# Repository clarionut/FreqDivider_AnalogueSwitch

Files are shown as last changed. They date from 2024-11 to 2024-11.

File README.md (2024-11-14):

# Frequency Divider / Analogue Switch

This repository contains details of synthesiser module providing a 4-stage frequency divider linked to three 2-in 2-out analogue changeover switches.

DividerSwitch

The frequency divider comprises two CD4027B Dual J-K flip-flops with each stage wired as a T-type flip-flop. Each stage toggles its state on the rising edge of its clock signal, converting the incoming pulse train into a square wave of half the incoming frequency. By default the output of each stage is normalled to the input of the next, so a single clock input can give four outputs of 1/2, 1/4, 1/8 and 1/16 the incoming frequency. Multiple input clocks can be processed using the input jacks on the later divider stages, e.g to divide one clock by 2 and a second clock by 2, 4 & 8. The outputs of each stage are 0-9V square waves.

The module also includes three 'two-pole changeover' analogue switches based on two CD4053B 3-channel mux/demux chips. The CD4053Bs are powered by +12 & -6V and consequently can handle Eurorack standard voltages of ±5V or 0-10V (with protection against out-of-range voltages) and will work with both CVs and audio-rate signals. Each of the virtual changeover switches can be connected to any of the four frequency divider stages and multiple switches can be connected to the same divider output. I used red/white bicolor LEDs to indicate the state of each changeover switch; when the control input to a switch is high its LED is white and the two inputs connect straight to the outputs and when low the LED is red and the inputs cross over to the outputs.

The original inspiration for this module was to provide a means of using my [ADCequencer](https://github.com/clarionut/ADCequencer) 8-step 2-channel sequencer as a 16-step 1-channel sequencer. Passing the two analogue outputs of the sequencer through a changeover switch clocked at 1/16 the speed of the sequencer swaps between the two outputs every 8 steps creating a 16 step sequence. Interesting variations can also be introduced by changing the relative phasing of the sequencer and the analogue switch. The frequency divider has a manual clock input to allow such changes on the fly.

##Hardware Notes

My synth is Eurorack format and to save space I used small 2-pole 4-way slide switches as the selectors connecting the analogue switches to the divider output stages. Unfortunately these are make-before-break which can cause glitching when switching on the fly. If you build in a larger format like Kosmo it would be better to use small break-before-make rotary switches for these selectors. If you're forced to use make-before-break switches it's best to set them up when all the divider outputs are in the same (high or low) state. Note that it's also extremely fiddly wiring the connections between the switch/LED sub-boards if you use the small slide switches!

##KiCad files

The schematic and PCB files are provided in KiCad 7 format and as PDFs. Note that the front copper ground plane is excluded from the board PDF for clarity but is present in the KiCad files. The schematic uses some custom symbols and the PCB some custom footprints, so you will need to download my [custom KiCad libraries](https://github.com/clarionut/kiCad_libraries) and tell KiCad where to find them. The PCB file is intended to be processed by the KiCad 'Round Tracks' plugin but will work perfectly well without. I've included the Gerber files but these will only be useful if you mount the PCB on brackets behind and perpendicular to the front panel.

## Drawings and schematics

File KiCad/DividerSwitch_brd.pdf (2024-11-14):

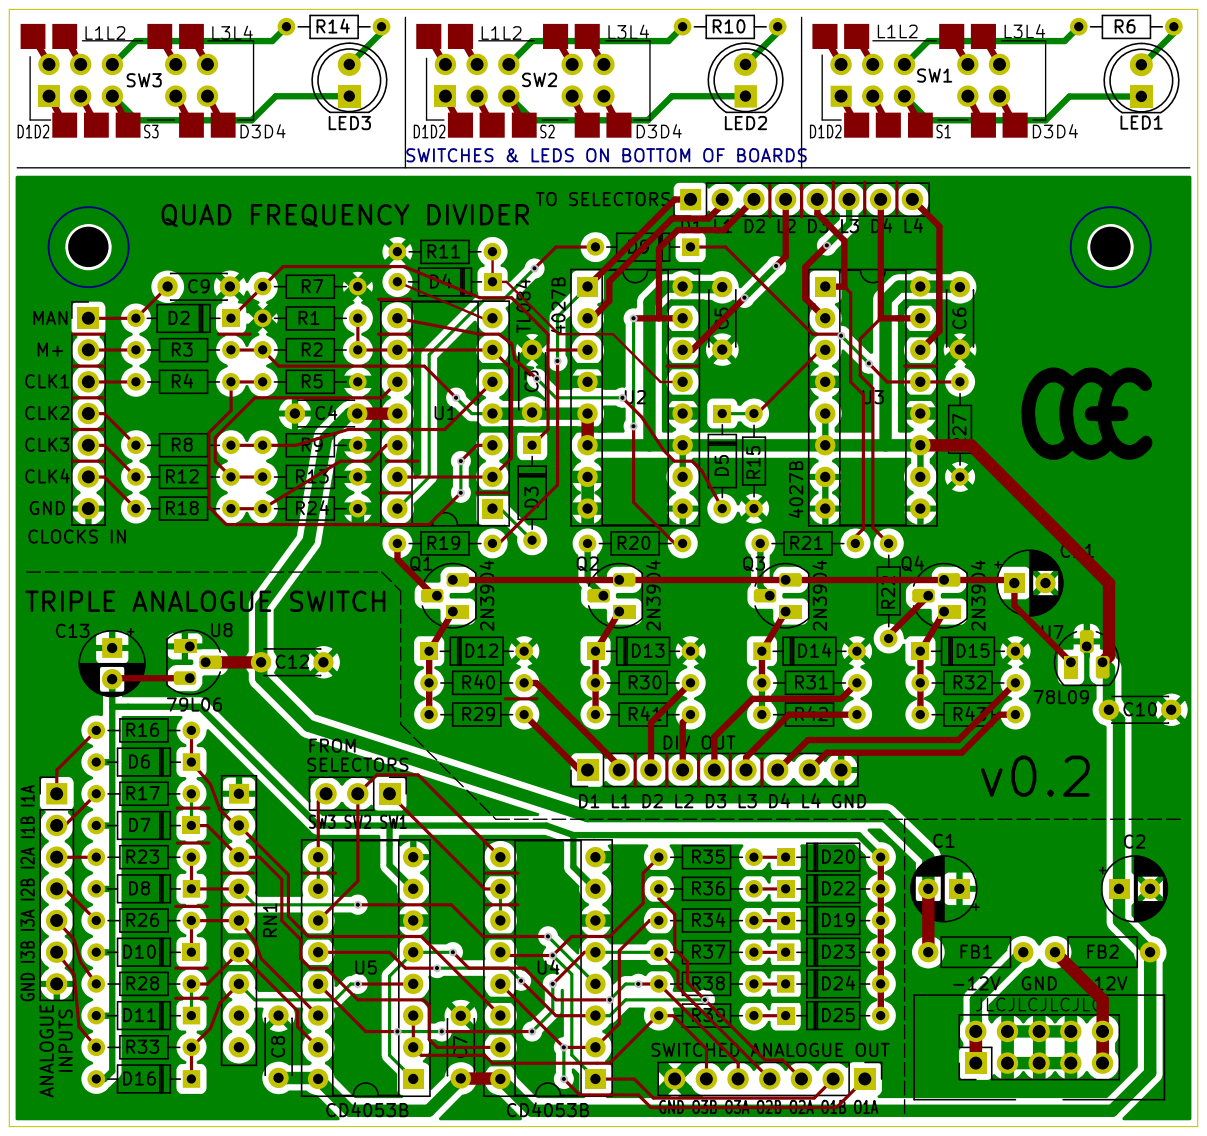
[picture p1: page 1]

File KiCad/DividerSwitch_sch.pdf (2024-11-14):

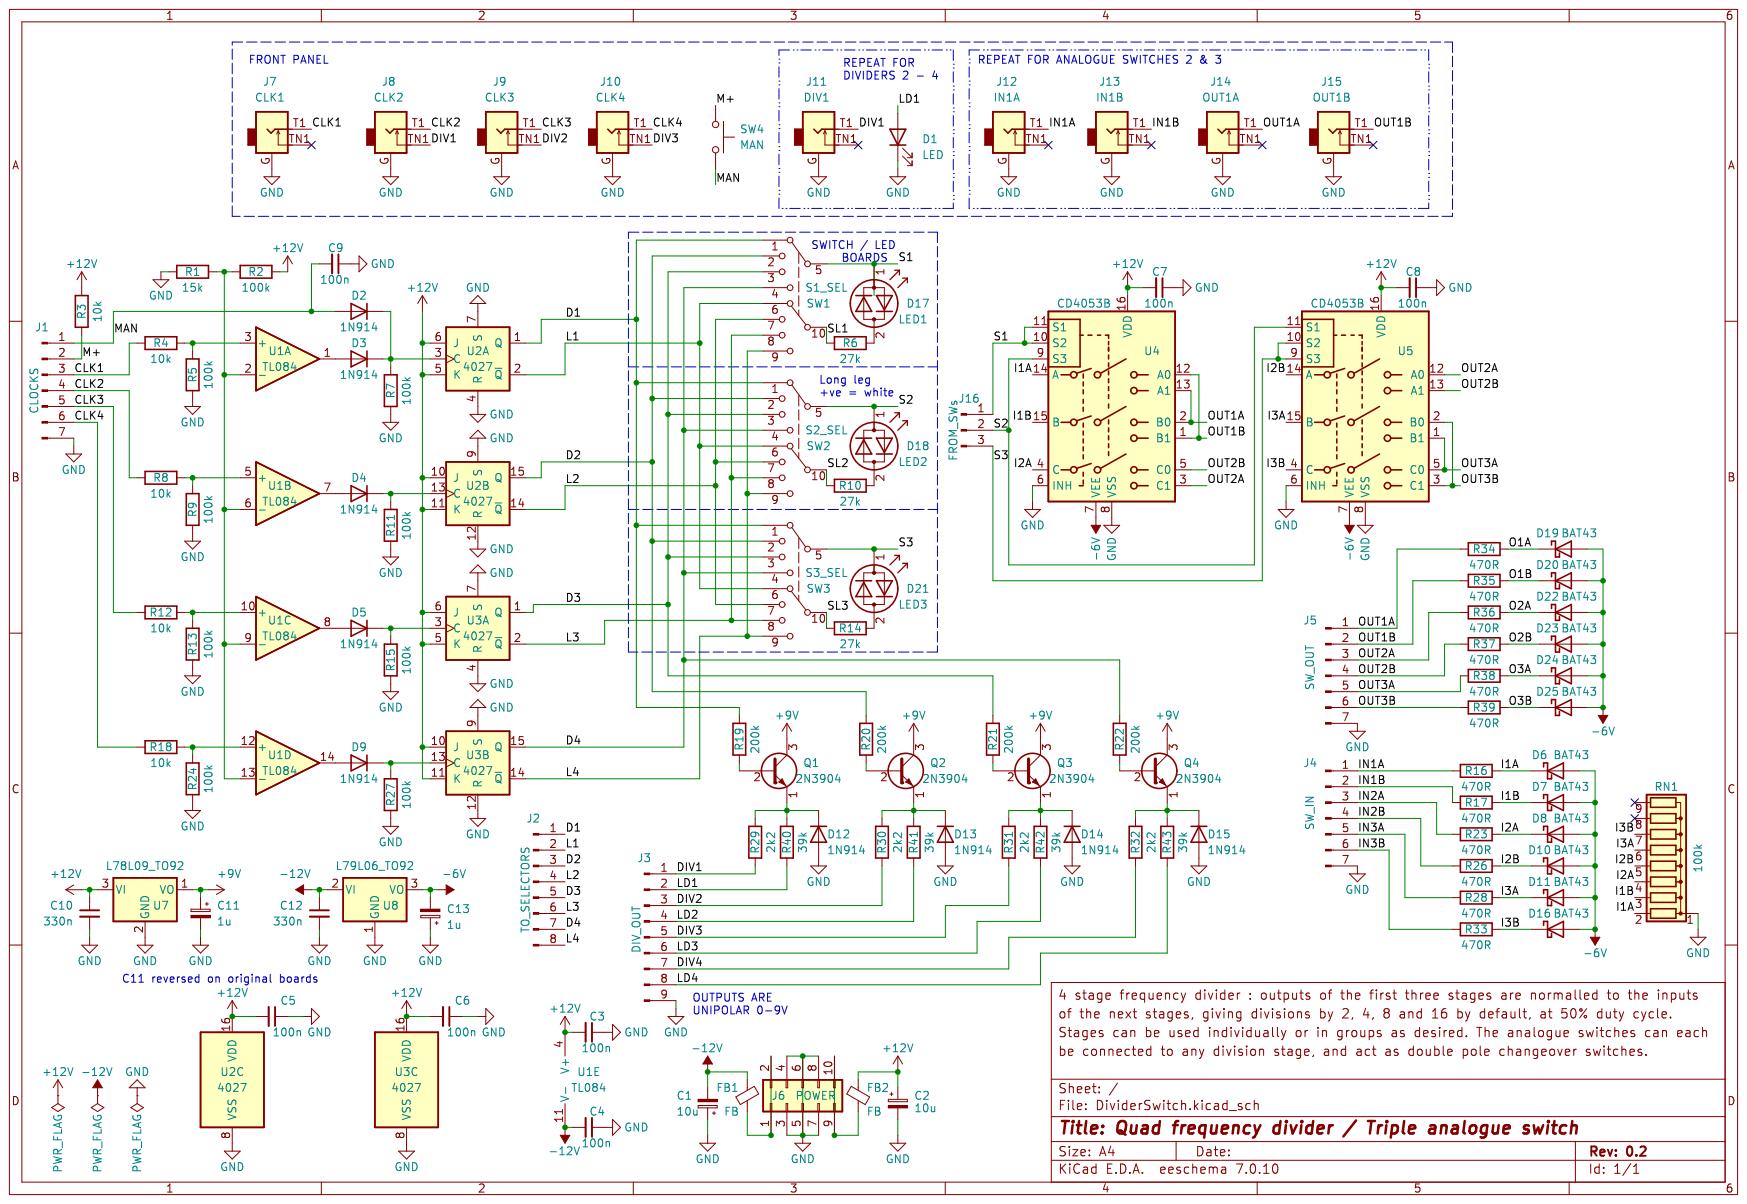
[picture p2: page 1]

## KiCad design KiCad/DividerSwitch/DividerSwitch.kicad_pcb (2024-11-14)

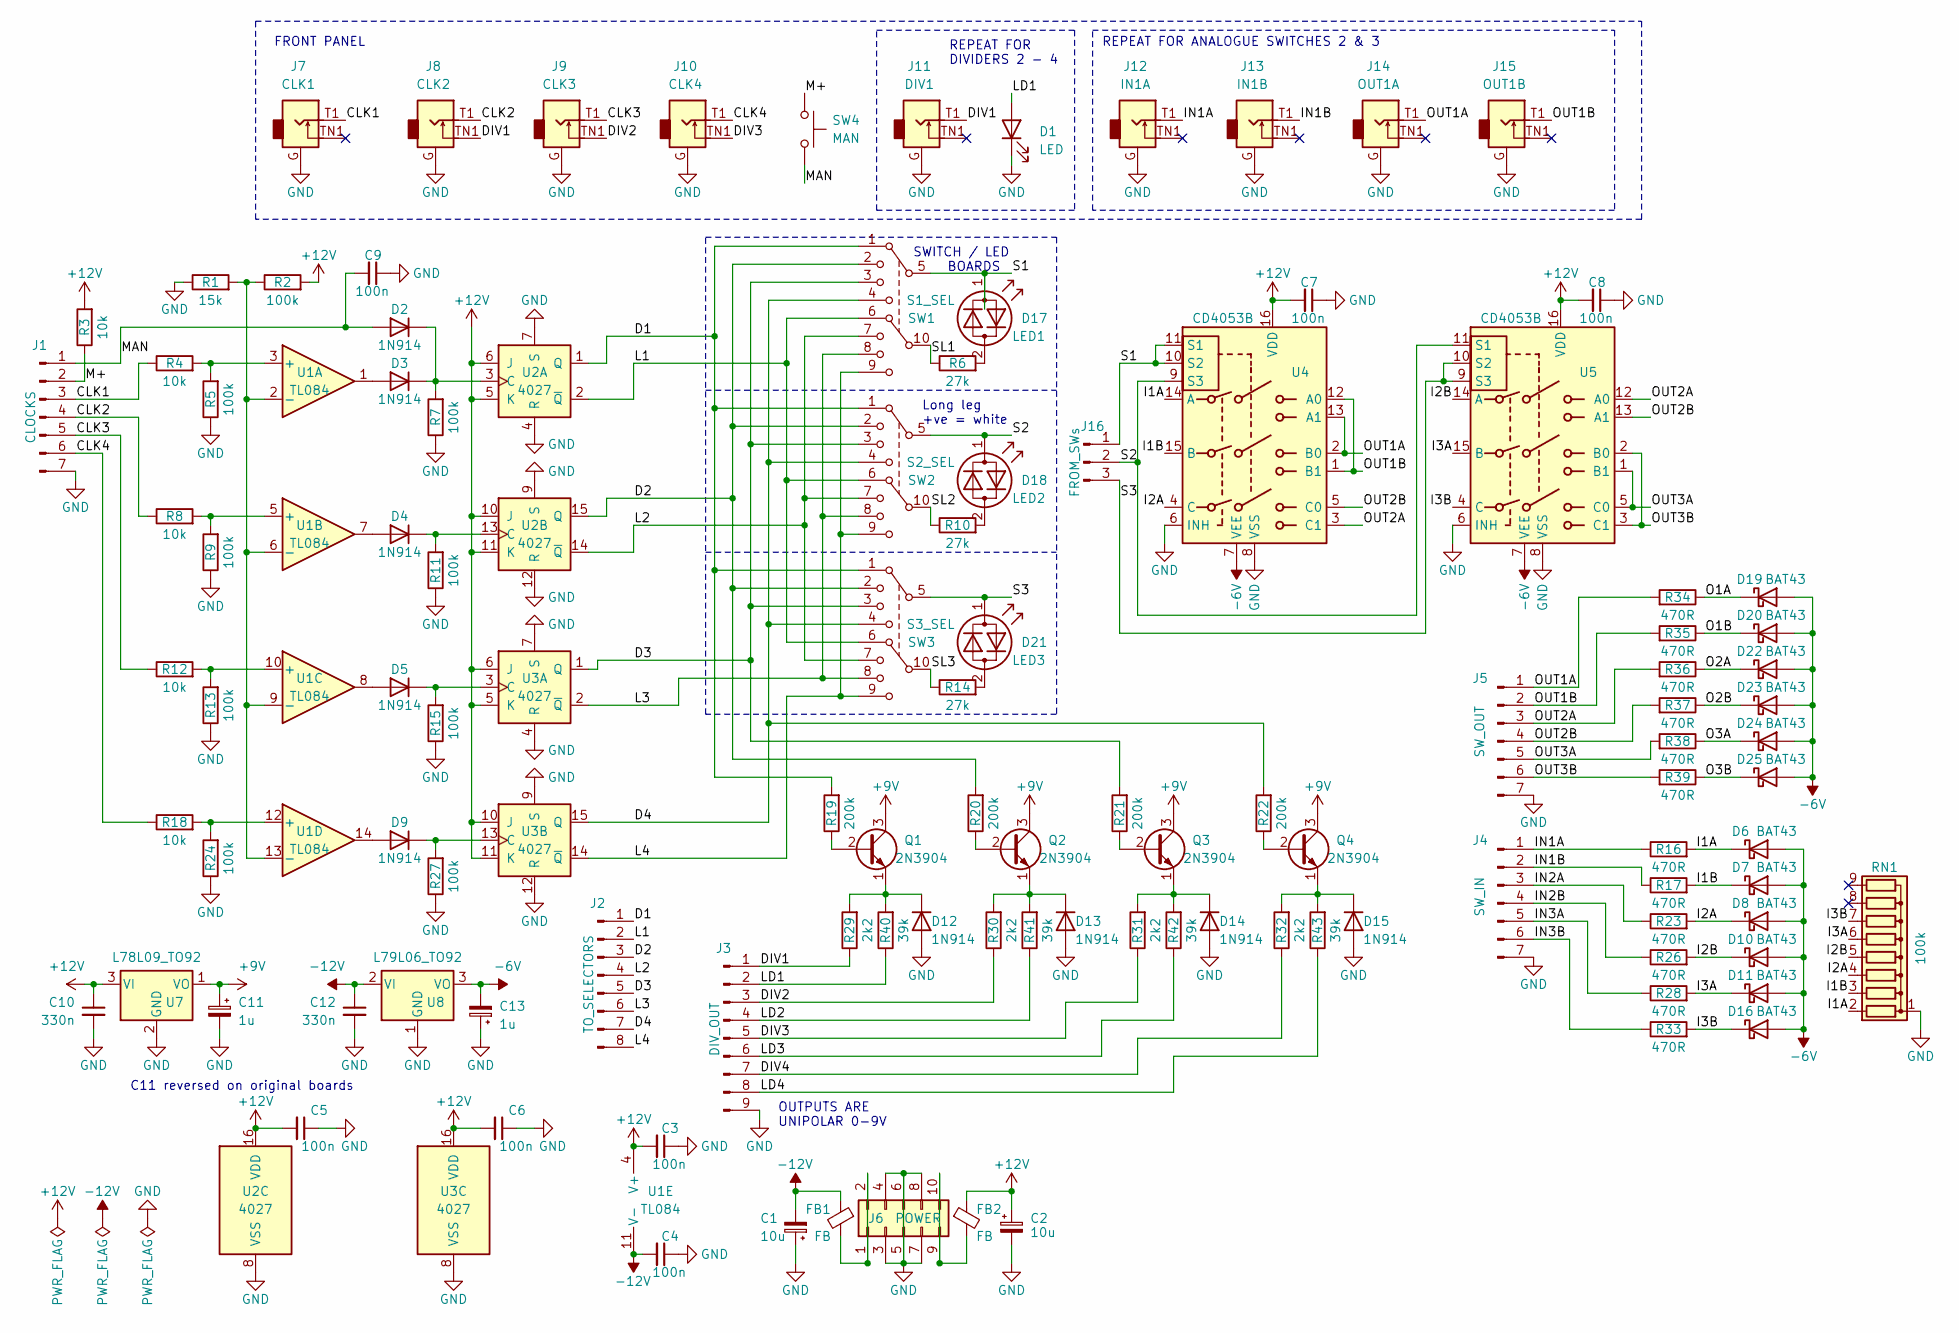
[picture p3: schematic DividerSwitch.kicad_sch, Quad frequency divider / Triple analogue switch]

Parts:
C1, C2: 10u; CP_Radial_D5.0mm_P2.50mm
C3, C4, C5, C6, C7, C8, C9: 100n; C_Disc_D4.3mm_W1.9mm_P5.00mm
C10, C12: 330n; C_Disc_D4.3mm_W1.9mm_P5.00mm
C11, C13: 1u; CP_Radial_D5.0mm_P2.50mm
D1: LED
D2, D3, D4, D5, D9, D12, D13, D14, D15: 1N914; D_DO-35_SOD27_P7.62mm_Horizontal
D6, D7, D8, D10, D11, D16, D19, D20, D22, D23, D24, D25: BAT43; D_DO-35_SOD27_P7.62mm_Horizontal
D17: LED1; LED_D5.0mm
D18: LED2; LED_D5.0mm
D21: LED3; LED_D5.0mm
FB1, FB2: FB; L_Axial_L5.3mm_D2.2mm_P7.62mm_Horizontal_Vishay_IM-1
J1: CLOCKS; PinHeader_1x07_P2.54mm_Vertical
J2: TO_SELECTORS; PinHeader_1x08_P2.54mm_Vertical
J3: DIV_OUT; PinHeader_1x09_P2.54mm_Vertical
J4: SW_IN; PinHeader_1x07_P2.54mm_Vertical
J5: SW_OUT; PinHeader_1x07_P2.54mm_Vertical
J6: POWER; Power_2x05
J7: CLK1
J8: CLK2
J9: CLK3
J10: CLK4
J11: DIV1
J12: IN1A
J13: IN1B
J14: OUT1A
J15: OUT1B
J16: FROM_SWs; PinHeader_1x03_P2.54mm_Vertical
Q1, Q2, Q3, Q4: 2N3904; TO-92_HandSolder
R1: 15k; R_Axial_DIN0204_L3.6mm_D1.6mm_P7.62mm_Horizontal
R2, R5, R7, R9, R11, R13, R15, R24, R27: 100k; R_Axial_DIN0204_L3.6mm_D1.6mm_P7.62mm_Horizontal
R3, R4, R8, R12, R18: 10k; R_Axial_DIN0204_L3.6mm_D1.6mm_P7.62mm_Horizontal
R6, R10, R14: 27k; R_Axial_DIN0204_L3.6mm_D1.6mm_P7.62mm_Horizontal
R16, R17, R23, R26, R28, R33, R34, R35, R36, R37, R38, R39: 470R; R_Axial_DIN0204_L3.6mm_D1.6mm_P7.62mm_Horizontal
R19, R20, R21, R22: 200k; R_Axial_DIN0204_L3.6mm_D1.6mm_P7.62mm_Horizontal
R29, R30, R31, R32: 2k2; R_Axial_DIN0204_L3.6mm_D1.6mm_P7.62mm_Horizontal
R40, R41, R42, R43: 39k; R_Axial_DIN0204_L3.6mm_D1.6mm_P7.62mm_Horizontal
RN1: 100k; R_Array_SIP9
SW1: S1_SEL; SW_DP4T_slide
SW2: S2_SEL; SW_DP4T_slide
SW3: S3_SEL; SW_DP4T_slide
SW4: MAN
U1: TL084; DIP-14_W7.62mm_Socket
U2, U3: 4027; DIP-16_W7.62mm_Socket
U4, U5: CD4053B; DIP-16_W7.62mm_Socket
U7: L78L09_TO92; TO-92_HandSolder
U8: L79L06_TO92; TO-92_HandSolder

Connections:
+9V: C11.1, Q1.3 (C), Q2.3 (C), Q3.3 (C), Q4.3 (C), U7.1 (VO)
+12V: C2.1, C3.2, C5.2, C6.2, C7.2, C8.2, C10.1, FB2.1, R2.2, R3.2, U1.4 (V+), U2.5 (K), U2.6 (J), U2.10 (J), U2.11 (K), U2.16 (VDD), U3.5 (K), U3.6 (J), U3.10 (J), U3.11 (K), U3.16 (VDD), U4.16 (VDD), U5.16 (VDD), U7.3 (VI)
-6V: C13.2, D6.2 (A), D7.2 (A), D8.2 (A), D10.2 (A), D11.2 (A), D16.2 (A), D19.2 (A), D20.2 (A), D22.2 (A), D23.2 (A), D24.2 (A), D25.2 (A), U4.7 (VEE), U5.7 (VEE), U8.3 (VO)
-12V: C1.2, C4.2, C12.1, FB1.1, U1.11 (V-), U8.2 (VI)
/CLK1: J1.3, J7.T1, R4.1
/CLK2: J1.4, J8.T1, R8.1
/CLK3: J1.5, J9.T1, R12.1
/CLK4: J1.6, J10.T1, R18.1
/D1: J2.1, R19.2, SW1.1, SW2.1, SW3.1, U2.1 (Q)
/D2: J2.3, R20.2, SW1.2, SW2.2, SW3.2, U2.15 (Q)
/D3: J2.5, R21.2, SW1.3, SW2.3, SW3.3, U3.1 (Q)
/D4: J2.7, R22.2, SW1.4, SW2.4, SW3.4, U3.15 (Q)
/DIV1: J3.1, J8.TN1, J11.T1, R29.1
/DIV2: J3.3, J9.TN1, R30.1
/DIV3: J3.5, J10.TN1, R31.1
/DIV4: J3.7, R32.1
/I1A: D6.1 (K), R16.2, RN1.2 (R1), U4.14 (A)
/I1B: D7.1 (K), R17.2, RN1.3 (R2), U4.15 (B)
/I2A: D8.1 (K), R23.2, RN1.4 (R3), U4.4 (C)
/I2B: D10.1 (K), R26.2, RN1.5 (R4), U5.14 (A)
/I3A: D11.1 (K), R28.2, RN1.6 (R5), U5.15 (B)
/I3B: D16.1 (K), R33.2, RN1.7 (R6), U5.4 (C)
/IN1A: J4.1, J12.T1, R16.1
/IN1B: J4.2, J13.T1, R17.1
/IN2A: J4.3, R23.1
/IN2B: J4.4, R26.1
/IN3A: J4.5, R28.1
/IN3B: J4.6, R33.1
/L1: J2.2, SW1.6, SW2.6, SW3.6, U2.2 (~Q)
/L2: J2.4, SW1.7, SW2.7, SW3.7, U2.14 (~Q)
/L3: J2.6, SW1.8, SW2.8, SW3.8, U3.2 (~Q)
/L4: J2.8, SW1.9, SW2.9, SW3.9, U3.14 (~Q)
/LD1: D1.2 (A), J3.2, R40.1
/LD2: J3.4, R41.1
/LD3: J3.6, R42.1
/LD4: J3.8, R43.1
/M+: J1.2, R3.1, SW4.1
/MAN: C9.2, D2.2 (A), J1.1, SW4.2
/O1A: D19.1 (K), R34.1
/O1B: D20.1 (K), R35.1
/O2A: D22.1 (K), R36.1
/O2B: D23.1 (K), R37.1
/O3A: D24.1 (K), R38.1
/O3B: D25.1 (K), R39.1
/OUT1A: J5.1, J14.T1, R34.2, U4.2 (B0), U4.13 (A1)
/OUT1B: J5.2, J15.T1, R35.2, U4.1 (B1), U4.12 (A0)
/OUT2A: J5.3, R36.2, U4.3 (C1), U5.12 (A0)
/OUT2B: J5.4, R37.2, U4.5 (C0), U5.13 (A1)
/OUT3A: J5.5, R38.2, U5.1 (B1), U5.5 (C0)
/OUT3B: J5.6, R39.2, U5.2 (B0), U5.3 (C1)
/S1: D17.1 (KA), J16.1, SW1.5, U4.10 (S2), U4.11 (S1)
/S2: D18.1 (KA), J16.2, SW2.5, U4.9 (S3), U5.11 (S1)
/S3: D21.1 (KA), J16.3, SW3.5, U5.9 (S3), U5.10 (S2)
/SL1: R6.1, SW1.10
/SL2: R10.1, SW2.10
/SL3: R14.1, SW3.10
GND: C1.1, C2.2, C3.1, C4.1, C5.1, C6.1, C7.1, C8.1, C9.1, C10.2, C11.2, C12.2, C13.1, D1.1 (K), D12.2 (A), D13.2 (A), D14.2 (A), D15.2 (A), J1.7, J3.9, J4.7, J5.7, J6.3, J6.4, J6.5, J6.6, J6.7, J6.8, J7.G, J8.G, J9.G, J10.G, J11.G, J12.G, J13.G, J14.G, J15.G, R1.1, R5.1, R7.1, R9.1, R11.1, R13.1, R15.1, R24.1, R27.1, RN1.1 (common), U2.4 (R), U2.7 (S), U2.8 (VSS), U2.9 (S), U2.12 (R), U3.4 (R), U3.7 (S), U3.8 (VSS), U3.9 (S), U3.12 (R), U4.6 (INH), U4.8 (VSS), U5.6 (INH), U5.8 (VSS), U7.2 (GND), U8.1 (GND)
unnamed: D2.1 (K), D3.1 (K), R7.2, U2.3 (C)
unnamed: D3.2 (A), U1.1
unnamed: D4.2 (A), U1.7
unnamed: D4.1 (K), R11.2, U2.13 (C)
unnamed: D5.2 (A), U1.8
unnamed: D5.1 (K), R15.2, U3.3 (C)
unnamed: D9.2 (A), U1.14
unnamed: D9.1 (K), R27.2, U3.13 (C)
unnamed: D12.1 (K), Q1.1 (E), R29.2, R40.2
unnamed: D13.1 (K), Q2.1 (E), R30.2, R41.2
unnamed: D14.1 (K), Q3.1 (E), R31.2, R42.2
unnamed: D15.1 (K), Q4.1 (E), R32.2, R43.2
unnamed: D17.2 (AK), R6.2
unnamed: D18.2 (AK), R10.2
unnamed: D21.2 (AK), R14.2
unnamed: FB1.2, J6.1, J6.2
unnamed: FB2.2, J6.9, J6.10
unnamed: Q1.2 (B), R19.1
unnamed: Q2.2 (B), R20.1
unnamed: Q3.2 (B), R21.1
unnamed: Q4.2 (B), R22.1
unnamed: R4.2, R5.2, U1.3 (+)
unnamed: R1.2, R2.1, U1.2 (-), U1.6 (-), U1.9 (-), U1.13 (-)
unnamed: R8.2, R9.2, U1.5 (+)
unnamed: R12.2, R13.2, U1.10 (+)
unnamed: R18.2, R24.2, U1.12 (+)

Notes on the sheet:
C11 reversed on original boards
REPEAT FOR ANALOGUE SWITCHES 2 & 3
FRONT PANEL
SWITCH / LED BOARDS
Long leg +ve = white
OUTPUTS ARE UNIPOLAR 0-9V
REPEAT FOR DIVIDERS 2 - 4

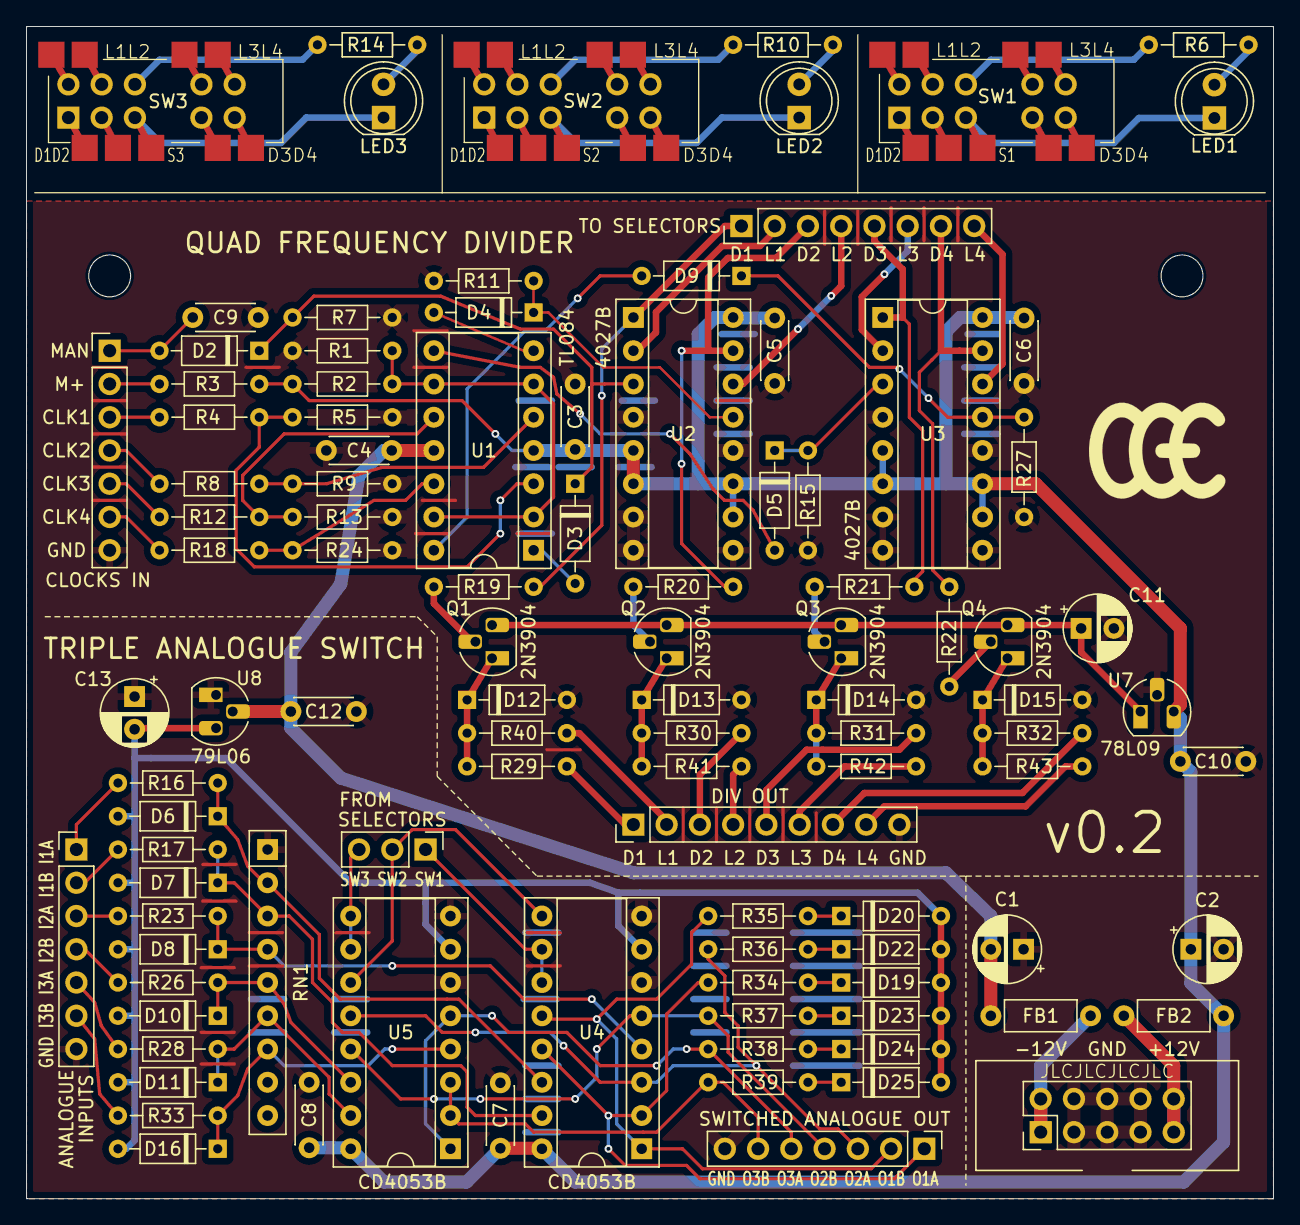
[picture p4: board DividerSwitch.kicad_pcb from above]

Board: 2 copper layers, 95.2 x 89.5 mm, 103 parts (0 on the bottom side), 83 nets.
